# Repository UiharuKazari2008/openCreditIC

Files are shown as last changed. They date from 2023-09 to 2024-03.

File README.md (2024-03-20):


# openCreditIC / PayPass
Cheap Networked RFID Reader(s) and cloud-free server for arcade cabinet credit payments. Uses card serial number for ID and local server to manage cards and balances

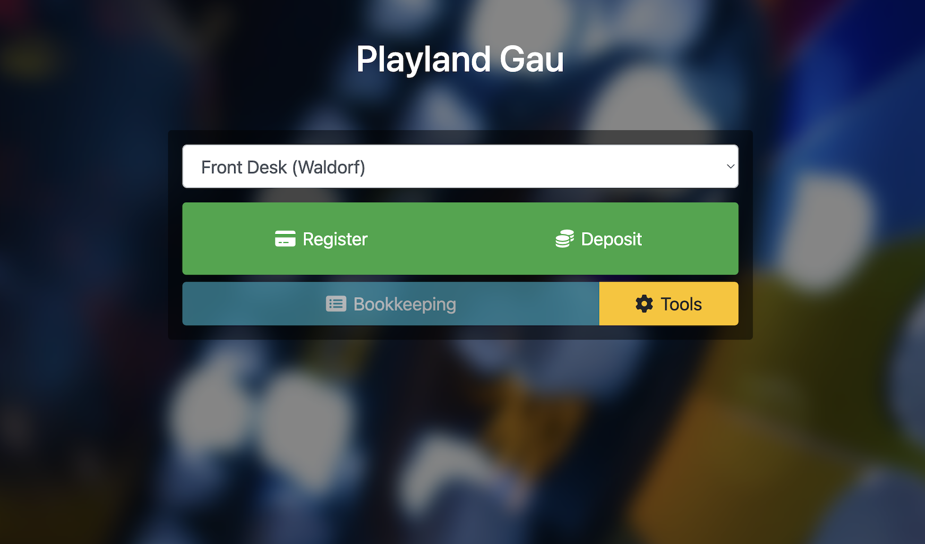
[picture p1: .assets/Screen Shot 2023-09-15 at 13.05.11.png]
Screen Shot 2023-09-15 at 13.05.11.png


## Sequenzia App Support





## NOTICE
At this time, I don't take responsibility for any damages caused if this is used commercially. Once this warning is removed you can consider the software to be "production" ready. More testing and feedback is still required

Please create issues to address feature requests and report bugs.

## Features
* ESP32-based RFID Card reader designed for low cast and easy build
* No Internet Access Required! *(after npm install)*
* Local Database
* Simple Web Interface for day to day tasks
* Per-User Multi-Card management
* Per-User Credit management
* Card and User Locking
* Toggleable Free Play (User, Machine, and Global)
* Per-machine Credit Cost
* Currency Mode Support (1 Credit = 100 Yen/Dollar/Euro)
* Cooldown and Anti-Hogging
  * X Credits per X Minutes
  * Anti-hogging can be used to set max number of credits per minutes to prevent hogging of cabinets
* Addressable POS Card Reader to provision cards and add credits
* Credit Withdraw History
* Credit Deposit History
* Supports multiple sites/locations
* HappyCAB MCU serial communication
  * Enable state toggle
  * Send coin blocker state
  * Use reader display for messageing 

## TODO
* VFD RS232 Communication (Currently requires AMaverlousDisplay)
* Encrypted communication

## Integrations
Supports various other ACR developed Arcade solutions
- AMaverlousDisplay: Displaying Information on WACCA Cabinets
- AmusementVISION: Displaying Information on video outputs
- Supports simple URL callbacks for:
  - On Credit Dispensed
  - On Valid Card Tap when Coin Blocked is activated
    - Example: Power on cabinet when powered off
- HappyCAB Cabinet MCU I/O and Display
- Connections to Sequenzia as a Embedded Application

## Installation
1. Install NodeJS on your system of choice
2. Clone this Git repo and cd into it
3. `npm install`
4. Create `config.json`
```json
{
  "arcade_name": "Arcade Name",
  "device_key": "API_KEY_FOR_CARD_READERS",
  "web_key": "WEB_ACCESS_API_KEY", /*If removed there is no login required*/
  "show_delete_actions": false /*Shows the Delete Card and Delete User Options*/
}
```
5. `node ./card-server.js`
6. Configure your arcade using the Configuration section
7. Open the web interface `http://localhost:1777/?key=WEB_ACCESS_API_KEY`

Use something like pm2 or systemd to run as a daemon 

## Example Card Reader Designs
Here are card readers that I have made and implemented as an example
### WACCA (Built into lower panel)
The card reader is mounted in the extra open window beside the coin slot<br/>
All The hardware in this example is in-assessable to the user<br/>
The relay is mounted flat to prevent bumping to insert credits<br/>
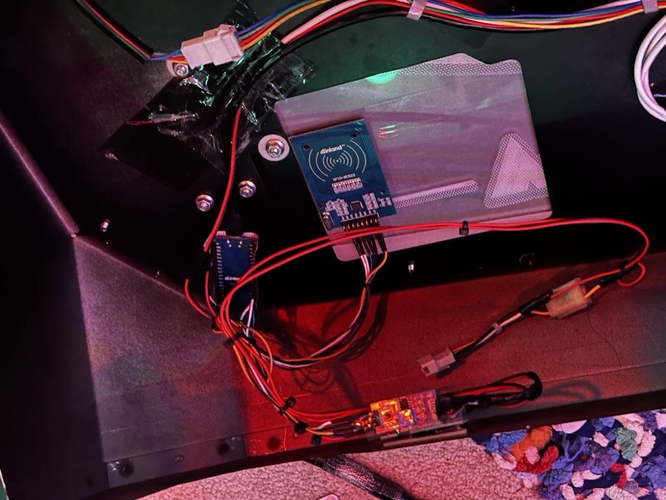
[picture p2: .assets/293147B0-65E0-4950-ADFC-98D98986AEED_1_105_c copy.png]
293147B0-65E0-4950-ADFC-98D98986AEED_1_105_c copy.png
<br/>

### Chunithm (Builtin to slider)
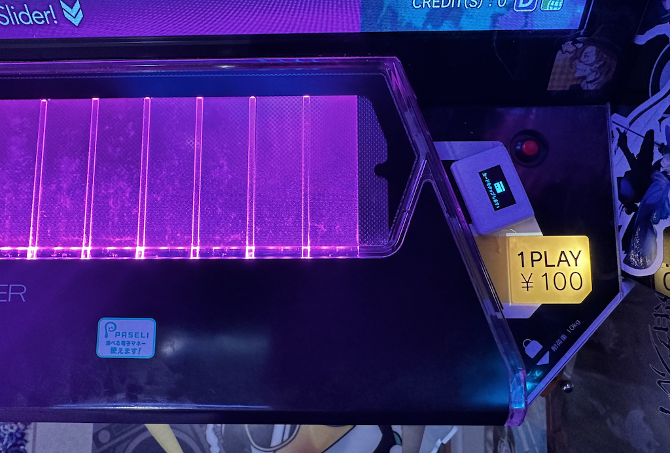
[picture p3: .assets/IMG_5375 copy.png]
IMG_5375 copy.png
<br/>
The card reader is mounted inside the ground slider, Foam backing is to prevent reader from getting to close to the metal backplate and causing issues with the reader<br/>
LED is mounted next to the "per play" indicator and is boxed to increase brightness<br/>
OLED Display is mounted over the coin slot<br/>
Button is added for future features<br/> 
The relay is mounted flat to prevent bumping to insert credits<br/>
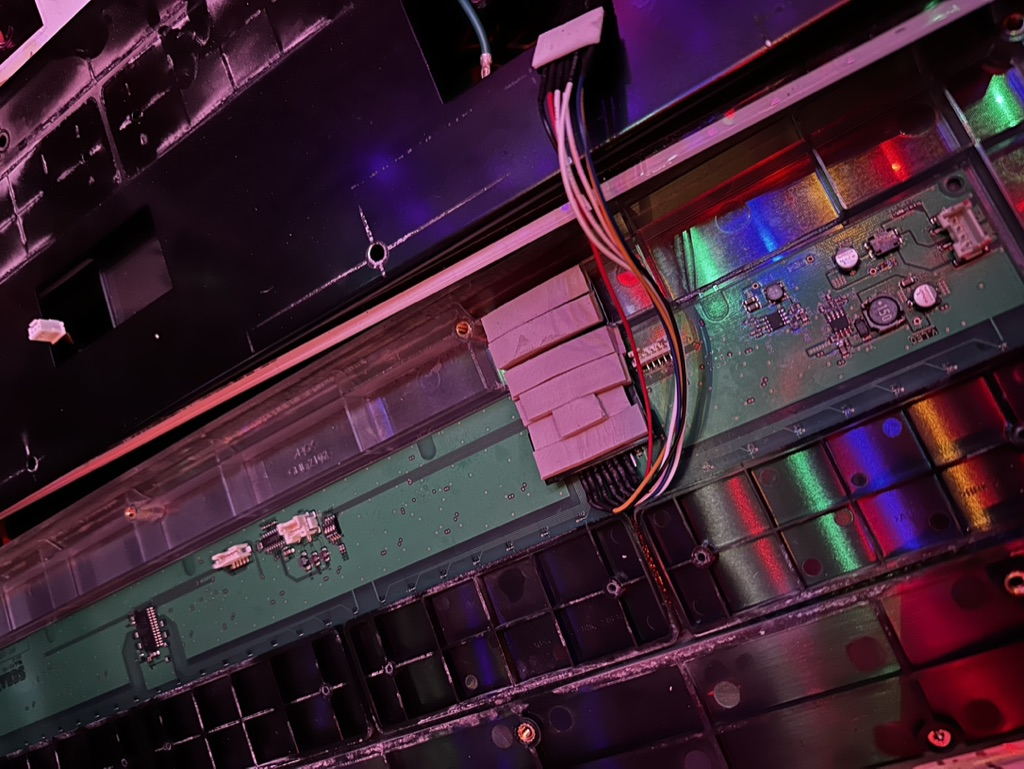
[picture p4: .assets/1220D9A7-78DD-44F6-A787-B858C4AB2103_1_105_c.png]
<br/>
10F6503A-9D1E-43A1-B554-D1E3282296A3_1_105_c copy.png<br/>

### POS Card Reader (with coin slot replacement reader)
Using the coin slot replacement reader design mounted on project box with the MCU inside.<br/>
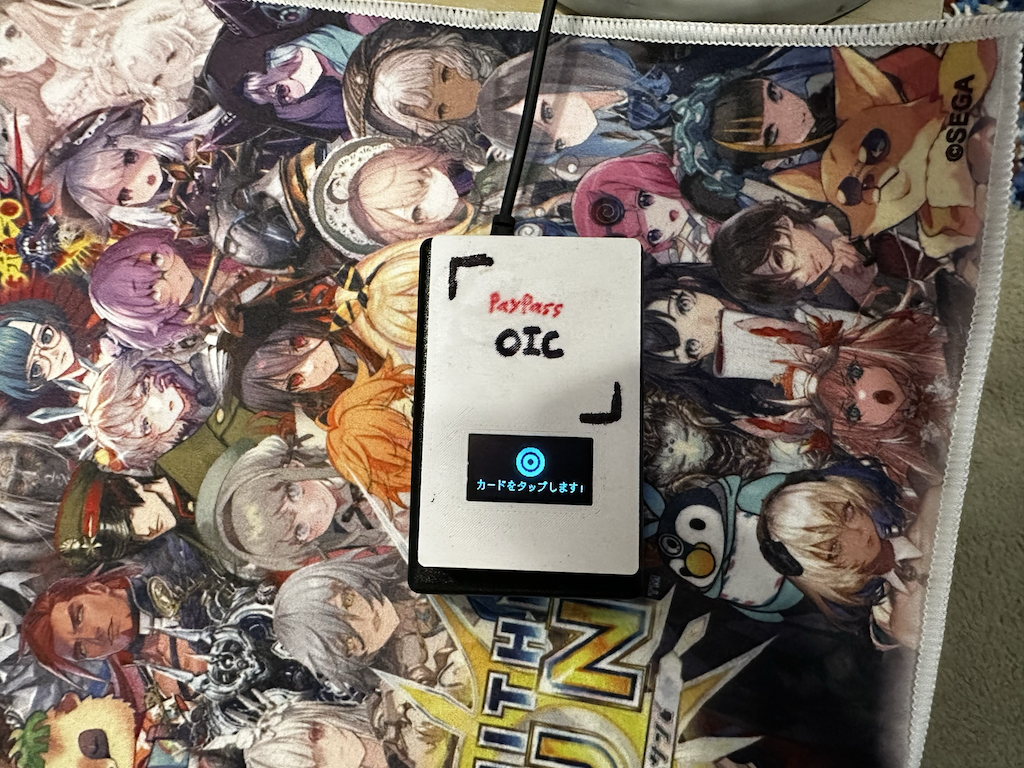
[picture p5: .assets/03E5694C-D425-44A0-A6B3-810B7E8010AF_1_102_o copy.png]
03E5694C-D425-44A0-A6B3-810B7E8010AF_1_102_o copy.png
<br/>
DED6BF8A-4EB7-40FF-B5D4-94D3E9F0AC93_1_102_o copy.png<br/>
Mounting screws are designed to work with most coin slots

## 3D printable designs
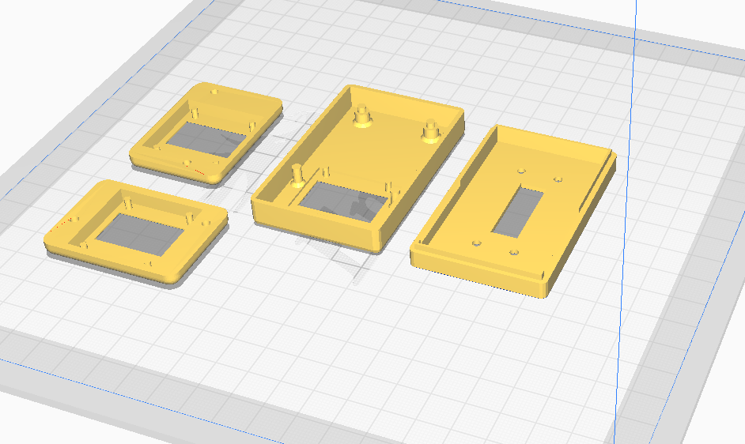
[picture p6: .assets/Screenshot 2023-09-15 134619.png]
Screenshot 2023-09-15 134619.png
<br/>
See the included STL files inside the `./printable` folder

## Card Reader Hardware
### Warning
It is expected that th card readers and the server are on there on dedicated wireless network in the case that this is running in a public arcade. As this is updated more security will be added.
### Configuration File
Create `config.h` inside the CardReader-* folder
```c
const char *ssid = "OCI_NET";
const char *password = "OCI_NET_SECURE029587";
const char *apiUrl = "http://192.168.0.2:1777/"; // URL to access central server
const char *deviceKey = "API_KEY_FOR_CARD_READERS"; // device_key from config.json

// Enable Remote Access
#define REMOTE_ACCESS
// Use Slimline 128x32 display
//#define DISPLAY_I2C_128x32
// Use alternative I2C card reader
//#define RFID_I2C
// Enable Multicore Tasking
#define MULTICORE_ENABLE
```
### Hardware
Any Optional hardware can be ommited and the reader will work the same
* ESP32 Dev Module
* RFID-RC522 RFID Module
* Credit Trigger
  * 5v/3.3v Relay with trigger on HIGH
  * or Optocoupler Isolation Board
* Coin Enable
  * LED + Digital LDR with trigger on HIGH
  * or Optocoupler Isolation Board (12v Input)
* RGB LED (WS2812) ***(Optional, Not Required)***
* OLED Display (SSD1306 128X64 I2C) ***(Optional, Suggested)***

### Pinout
* RFID-RC522
  * SDA/NSS/Slave Select -> **IO16**
  * SCK/Clock -> **IO18**
  * MOSI -> **IO23**
  * MISO -> **IO19**
  * GND -> **GND Bus**
  * RST -> **IO17**
  * 3.3v -> **3.3v Bus**
* Credit Add Relay
  * GND -> **GND Bus**
  * Trigger -> **IO13**
  * 5v -> **5v Bus**
* Coin Blocker
  * GND -> **GND Bus**
  * DO -> **IO14**
  * 3.3v -> **3.3v Bus**
* WS2812 Indicator LED *(Optional)*
  * GND -> **GND Bus**
  * IN -> **IO12**
  * 5v -> **5v Bus**
* I2C OLED Display *(Optional)*
  * GND -> **GND Bus**
  * SCL/Clock -> **IO22**
  * SDA/Data -> **IO21**
  * 5v -> **5v Bus**

### Flashing Firmware
* Connect via USB and launch Arduino IDE
* Install the following libraries
  * MFRC522
  * FastLED
  * ArduinoJSON
  * U8G2
* Open the project
  * CardReader-Game - Designed for games
  * CardReader-POS - Designed for POS reader (No Relay/No Coin Blocker)
* Set the following varibles
  * ssid - WiFi network Name
  * password - WiFi network password
  * apiUrl - IP/FQDN to access the server
  * deviceKey - device_key from config.json
* Build and Flash your card readers

## Configuration
Use the following URLs to set settings with your server<br/>
Add Commands need `key=API_KRY` to authenticate<br/>
* `/set/arcade/cost/<NUMBER>`: Set Per Play Cost
  * `/set/machine/cost/<MAC_ADDRESS>/<NUMBER>` (Per Machine)
* `/set/arcade/low_balance/<NUMBER>`: Set Low Balance Alert 
  * When users wallet balance falls below this number the display will display a warning and the LED will flash
* `/set/arcade/currency/<NUMBER>`: Set the currency to credit multiplier (use "null" as value to disable)
  * Once set Credits will be prefixed with Yen or Dollar symbol and will be multiplied based on that value
* `/set/arcade/freeplay/<enable or disable>`: Sets global freeplay mode
  * `/set/machine/freeplay/<MAC_ADDRESS>/<enable or disable>`: (Set Machine Freeplay)
* `/set/arcade/cooldown/<Credits:NUMBER>/<Minutes:NUMBER>`: Cooldown timeout - Sets max number of credits per X minutes
* `/set/arcade/antihog/<Credits:NUMBER>/<Minutes:NUMBER>`: Antihogging per machine timeout - Sets max number of credits per X minutes
  * `/set/machine/antihog/<Credits:NUMBER>/<Minutes:NUMBER>`: (Set Machine)
* `/set/arcade/japanese/<enable or disable>`: Enable Japanese Text and Currency
  * `/set/machine/japanese/<MAC_ADDRESS>/<enable or disable>`: (Set Machine)
* `/create/pos/<MAC_ADDRESS>`: Set up a POS reader
  * `name=`: Reader Name
  * `location=`: Reader Location

### Advanced
* `/set/machine/vfd/<MAC_ADDRESS>/<VFD_IP>/<VFD_PORT>`: Set VFD connection
* `/set/machine/blocked_callback/<MAC_ADDRESS>/<URL_ENCODED_URL>`: URL to call on blocked tap
* `/set/machine/withdraw_callback/<MAC_ADDRESS>/<URL_ENCODED_URL>`: URL to call on credit dispensed

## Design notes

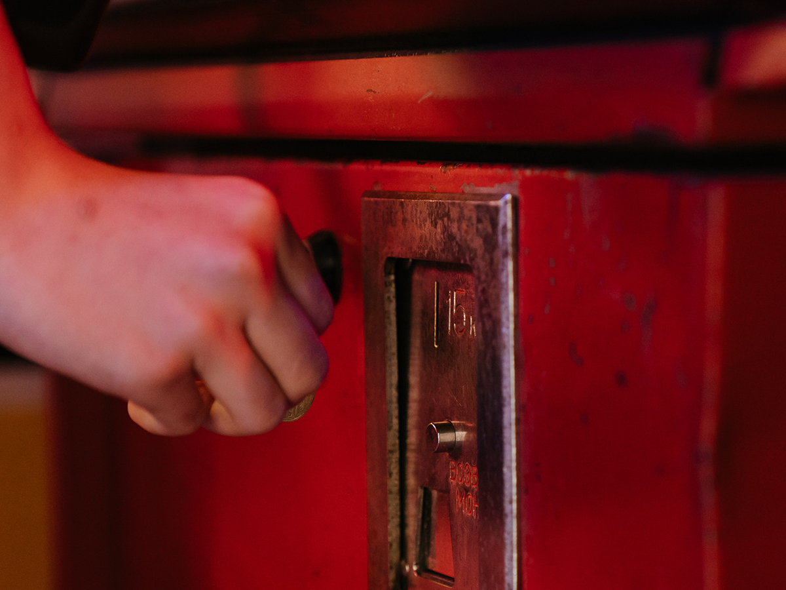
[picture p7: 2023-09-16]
ui_images/seq-launch.jpg

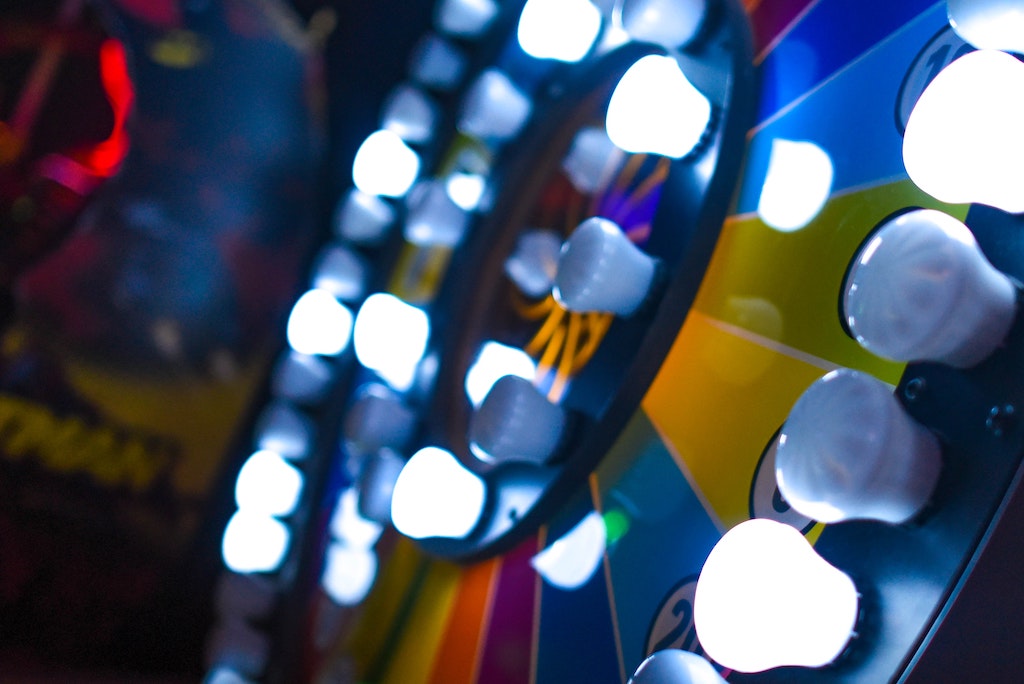
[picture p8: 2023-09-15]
ui_images/background.jpg

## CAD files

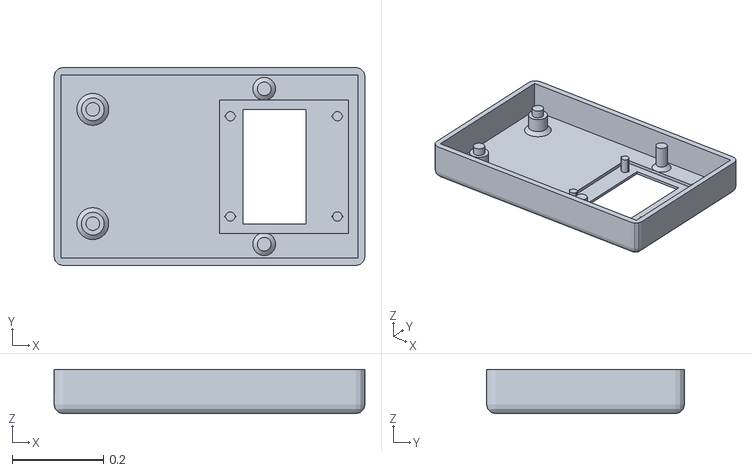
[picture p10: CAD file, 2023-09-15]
printable/chun_coin_with_display_landscape_case.stl
0.681 x 0.434 x 0.0969

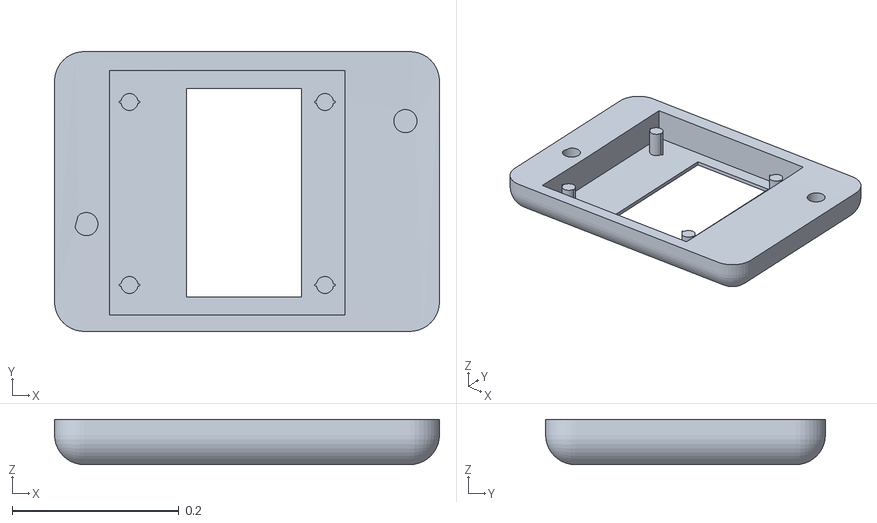
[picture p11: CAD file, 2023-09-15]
printable/chun_coin_with_display_landscape.stl
0.462 x 0.336 x 0.0543

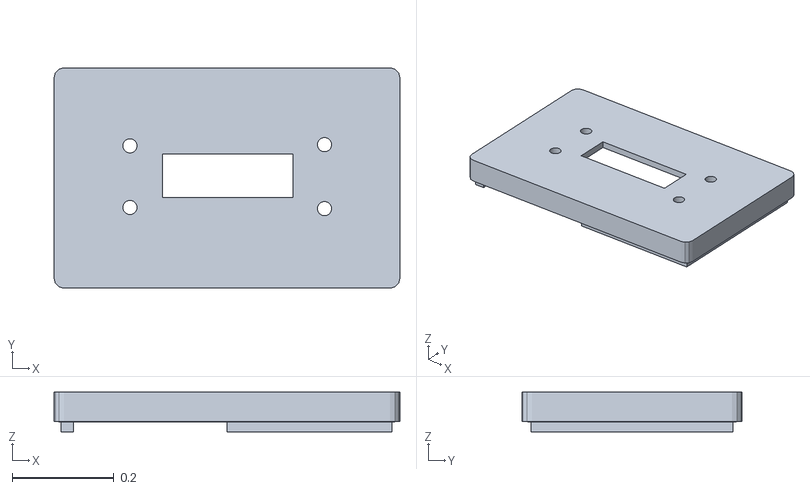
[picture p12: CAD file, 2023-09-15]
printable/chun_coin_with_display_landscape_case_back.stl
0.68 x 0.434 x 0.0786

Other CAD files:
printable/chun_coin_with_display.stl

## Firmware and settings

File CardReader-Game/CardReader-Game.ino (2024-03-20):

#include <Wire.h>
#include <Adafruit_PN532.h>
#include <SPI.h>
#include <MFRC522.h>
#include <WebServer.h>
#include <WiFi.h>
#include <HTTPClient.h>
#include <U8g2lib.h>  // Include the U8g2 library for OLED display.
#include <ArduinoJson.h>
#include <FastLED.h>
#include "images.h"
#include "config.h"
#include "melody.h"

#define SS_PIN 5      // Define the SS pin (Slave Select) for the RFID module.
#define RST_PIN 15     // Define the RST pin for the RFID module.
#define RELAY_PIN 13   // Define the pin connected to the relay.
#define BLOCK_PIN 14   // Define the pin connected to the LDR for Coin Blocking from cab
#define BUTTON_PIN 4   // Button used for front panel button
#define LED_PIN 12     // Define the pin connected to the WS2812 LED strip.
#define NUM_LEDS 1     // Define the number of LEDs in the strip.
#define HAPPYCAB_TX 2 // Define the pin to communicate with the cabinet MCU (if used)
#define HAPPYCAB_RX 4 // Define the pin to communicate with the cabinet MCU (if used)
#define LONG_PRESS_TIME 1 // Define long press time (sec) for long press action on button
#define EXTRA_PRESS_TIME 3 // Define long press time (sec) for long press action on button

CRGB leds[NUM_LEDS];  // Create an array of CRGB colors for the LEDs.
#ifdef RFID_I2C
Adafruit_PN532 nfc(21, 22);
#else
MFRC522 mfrc522(SS_PIN, RST_PIN);  // Create an MFRC522 instance.
#endif

#ifdef DISPLAY_I2C_128x32
U8G2_SSD1306_128X32_UNIVISION_F_HW_I2C u8g2(U8G2_R0);
#else
U8G2_SSD1306_128X64_NONAME_F_HW_I2C u8g2(U8G2_R0);
#endif
#ifdef REMOTE_ACCESS
WebServer server(80);
#endif
#ifdef HAPPYCAB_ENABLE
HardwareSerial cardReaderSerial(2);
#endif
TaskHandle_t Task1;
TaskHandle_t Task2;
TaskHandle_t Task3;
TaskHandle_t Task4;

int enableState = 0;
int blockState = 0;
int blockOverride = 0;
int displayState = -1;
bool waitingForUnblock = false;
bool lastButtonState = false;
bool handledButtonState = false;
unsigned long buttonPressStartTime = 0;
int mcuState = -1;
int displayTimeout = 0;
int previousDisplayTimeout = 0;
int typeOfMessage = -1;
int messageIcon = 0;
String messageText = "";
bool isJpnMessage = false;
int brightMessage = 1;
bool invertMessage = false;

int lastCheckIn = 0;

char* sys_name = "";
bool sys_jpn = false;
bool sys_free_play = false;
bool sys_currency_mode = false;
bool sys_button_remote_action = false;
float sys_currency_rate = 1;
float sys_cost = 1;
bool sys_callbackOnBlockedTap = false;

void setup() {
  Serial.begin(115200);
  pinMode(RELAY_PIN, OUTPUT);
  pinMode(21, OUTPUT);
  pinMode(22, OUTPUT);
  pinMode(BLOCK_PIN, INPUT);
  pinMode(BUTTON_PIN, INPUT_PULLUP);
  digitalWrite(RELAY_PIN, LOW);                           // Initially, set the relay to OFF.
  FastLED.addLeds<WS2812, LED_PIN, GRB>(leds, NUM_LEDS);  // Initialize the LED strip.
  u8g2.begin();
  u8g2.enableUTF8Print();
  setLEDs(CRGB::Black);
  FastLED.setBrightness(255);
  FastLED.clear();
  FastLED.show();
  bootScreen("HARDWARE");
  #ifdef RFID_I2C
    Wire.begin(21, 22);
    nfc.begin();
    uint32_t versiondata = nfc.getFirmwareVersion();
    if (!versiondata) {
      Serial.println("Didn't find PN53x board");
      bootScreen("NFC FAILURE");
      while (1)
        ;
    }
    Serial.print("Found chip PN5");
    Serial.println((versiondata >> 24) & 0xFF, HEX);
    Serial.print("Firmware ver. ");
    Serial.print((versiondata >> 16) & 0xFF, DEC);
    Serial.print('.');
    Serial.println((versiondata >> 8) & 0xFF, DEC);
    nfc.setPassiveActivationRetries(0x0A);
    nfc.SAMConfig();
  #else
    SPI.begin();         // Initialize SPI communication.
    mfrc522.PCD_Init();  // Initialize the RFID module.
    mfrc522.PCD_SetAntennaGain(mfrc522.RxGain_48dB);
  #endif
  checkWiFiConnection();

  #ifdef REMOTE_ACCESS
    server.on("/test/block", [=]() {
      if (blockOverride == 0) {
        blockOverride = 1;
      } else {
        blockOverride = 0;
      }
      enableState = 1;
      Serial.print("Set coin blocker overide: ");
      Serial.println((blockOverride == 1) ? "Overided" : "Normal");
      server.send(200, "text/plain", (blockOverride == 1) ? "Overided Coin Enable" : "Normal Mode");
    });
    server.on("/enable", [=]() {
      enableState = 1;
      server.send(200, "text/plain", "OK");
    });
    server.on("/disable", [=]() {
      enableState = 0;
      server.send(200, "text/plain", "OK");
    });
    server.on("/status", [=]() {
      String assembledOutput = "";
      assembledOutput += ((enableState == 0) ? "Disabled" : ((blockState == 1) ? "Blocked" : "Enabled"));
      server.send(200, "text/plain", assembledOutput);
    });
    server.on("/credit", [=]() {
      String assembledOutput = "";
      handleDispenseCoin();
      server.send(200, "text/plain", "OK");
    });
    server.on("/reboot", [=]() {
      String assembledOutput = "";
      server.send(200, "text/plain", "OK");
      ESP.restart();
    });
    server.begin();
    Serial.println("Remote Access Enabled");
  #endif

  #ifdef HAPPYCAB_ENABLE
    bootScreen("CR_LINK");
    cardReaderSerial.begin(9600, SERIAL_8N1, 16, 17);
    if (!cardReaderSerial) {
      bootScreen("CARDREADER_FAIL_1");
      Serial.println("Serial Port did no load!");
      while (1) { // Don't continue with invalid configuration
        delay (1000);
      }
    } else {
      cardReaderSerial.println("HELLO::NO_DATA_ED_");
    }
    delay (500);
    enableState = 0;
  #else
    enableState = 1;
  #endif
  Serial.println("Reader is ready to init");
  #ifdef MULTICORE_ENABLE
    bootScreen("BOOT_HCCL");
    //create a task that will be executed in the Task2code() function, with priority 1 and executed on core 1
    xTaskCreatePinnedToCore(
                      cardReaderTXLoop,   /* Task function. */
                      "mcuTX",     /* name of task. */
                      10000,       /* Stack size of task */
                      NULL,        /* parameter of the task */
                      1,           /* priority of the task */
                      &Task3,      /* Task handle to keep track of created task */
                      1);          /* pin task to core 1 */
    delay(500);
    //create a task that will be executed in the Task2code() function, with priority 1 and executed on core 1
    xTaskCreatePinnedToCore(
                      cardReaderRXLoop,   /* Task function. */
                      "mcuRX",     /* name of task. */
                      10000,       /* Stack size of task */
                      NULL,        /* parameter of the task */
                      1,           /* priority of the task */
                      &Task4,      /* Task handle to keep track of created task */
                      1);          /* pin task to core 1 */
    delay(500);
    bootScreen("BOOT_CPU1");
    xTaskCreatePinnedToCore(
                      cpu2Loop,   /* Task function. */
                      "Watchdog",     /* name of task. */
                      10000,       /* Stack size of task */
                      NULL,        /* parameter of the task */
                      1,           /* priority of the task */
                      &Task1,      /* Task handle to keep track of created task */
                      0);          /* pin task to core 0 */
    delay(250);
    bootScreen("BOOT_CPU2");
    delay(250);
    //create a task that will be executed in the Task2code() function, with priority 1 and executed on core 1
    xTaskCreatePinnedToCore(
                      cpu1Loop,   /* Task function. */
                      "ReaderTask",     /* name of task. */
                      10000,       /* Stack size of task */
                      NULL,        /* parameter of the task */
                      1,           /* priority of the task */
                      &Task2,      /* Task handle to keep track of created task */
                      1);          /* pin task to core 1 */
    delay(500);
  #endif
}
void loop() {
  #ifdef MULTICORE_ENABLE
    // Handled by tasks
  #else
    int time_in_sec = esp_timer_get_time() / 1000000;
    if (time_in_sec >= 86400) {
      Serial.println("Daily Reboot");
      ESP.restart();
    } else if (lastCheckIn <= time_in_sec - 18000) {
      Serial.println("Check in");
      getConfig(false);
    }
    checkWiFiConnection();
    #ifdef REMOTE_ACCESS
      server.handleClient();
    #endif
    runtime();
  #endif
}

//////////////////////
// System Functions //
//////////////////////

// Check WiFi or Connect
void checkWiFiConnection() {
  if (WiFi.status() != WL_CONNECTED) {
    setLEDs(CRGB::Magenta);
    bootScreen("NETWORK");
    Serial.println("WiFi not connected. Attempting to reconnect...");
    WiFi.hostname("SimpleCard");
    WiFi.disconnect(true);
    WiFi.begin(ssid, password);
    WiFi.setAutoReconnect(true);
    WiFi.persistent(true);
    int tryCount = 0;
    while (WiFi.status() != WL_CONNECTED) {
      if (digitalRead(BUTTON_PIN) == LOW) {
        ESP.restart();
      }
      if (tryCount > 10) {
        ESP.restart();
      }
      delay(1000);
      Serial.print(".");
      tryCount++;
    }
    Serial.println("\nConnected to WiFi");
    Serial.print("IP address: ");
    Serial.println(WiFi.localIP());
    Serial.print("MAC address: ");
    Serial.println(WiFi.macAddress());
    bootScreen("CONFIG");
    getConfig(true);
    bootScreen("READY");
    delay(250);
  }
}
// Get Reader Config
void getConfig(bool firstStart) {
  Serial.println("Refreshing system config....");
  HTTPClient http;
  String url = String(apiUrl) + "get/machine/" + WiFi.macAddress() + ((firstStart == true) ? "/init" : "/checkin") + "?key=" + deviceKey;
  Serial.println("Sending GET request to: " + url);
  http.begin(url);
  int httpCode = http.GET();
  String httpResponse = http.getString();
  http.end();
  Serial.println("HTTP Response code: " + String(httpCode));
  if (httpCode == 200) {
    Serial.println(httpResponse);
    DynamicJsonDocument doc(1024);
    deserializeJson(doc, httpResponse);
    //sys_name = doc["name"];
    sys_cost = doc["cost"];
    sys_free_play = doc["free_play"];
    sys_currency_mode = doc["currency_mode"];
    sys_currency_rate = (sys_currency_mode == true) ? doc["currency_rate"] : 0;
    sys_jpn = doc["japanese"];
    sys_button_remote_action = doc["button_callback"];
    sys_callbackOnBlockedTap = doc["has_blocked_callback"];
    lastCheckIn = esp_timer_get_time() / 1000000;
  } else if (httpCode >= 400 && httpCode <= 499) {
    while(true) {
      if (firstStart == true) {
        bootScreen("AUTH FAIL");
        delay(5000);
        bootScreen(WiFi.macAddress());
        delay(60000);
        ESP.restart();
      } else {
        ESP.restart();
      }
    };
  } else {
    Serial.println("Can't get config");
    if (firstStart == true) {
      bootScreen("AUTH FAIL");
      delay(5000);
      ESP.restart();
    }
  }
}
// Gets Cards UID
String getUID() {
  String uid = "";
  #ifdef RFID_I2C
    uint8_t success;
    uint8_t uidValue[] = { 0, 0, 0, 0, 0, 0, 0 };
    uint8_t uidLength;
    success = nfc.readPassiveTargetID(PN532_MIFARE_ISO14443A, uidValue, &uidLength);
    if (success) {
      for (uint8_t i = 0; i < uidLength; i++) {
        uid += String(uidValue[i], HEX);
      }
      uid.toUpperCase();
    }
  #else
    for (byte i = 0; i < mfrc522.uid.size; i++) {
      uid += String(mfrc522.uid.uidByte[i], HEX);
    }
    uid.toUpperCase();
  #endif
  return uid;
}


//////////////////////
// Action Handelers //
//////////////////////

// Primary Loop function
#ifdef MULTICORE_ENABLE
void cpu1Loop( void * pvParameters ) {
  Serial.print("Primary Task running on core ");
  Serial.println(xPortGetCoreID());

  for(;;) {
    runtime();
  }
}
// Secoundary Loop Function
void cpu2Loop( void * pvParameters ) {
  Serial.print("Secoundary Task running on core ");
  Serial.println(xPortGetCoreID());

  for(;;) {
    int time_in_sec = esp_timer_get_time() / 1000000;
    int currentMillis = millis();
    if (time_in_sec >= 86400) {
      Serial.println("Daily Reboot");
      ESP.restart();
    } else if (lastCheckIn <= time_in_sec - 18000) {
      Serial.println("Check in");
      getConfig(false);
    }
    checkWiFiConnection();
    #ifdef BEEPER_ENABLE
    if (startMelody == true) {
      if (currentMillis - previousMelodyMillis >= pauseBetweenNotes) {
        previousMelodyMillis = currentMillis;
        if (melodyPlay == 0) {
          playMelody(credit_tone, credit_tone_dur, sizeof(credit_tone_dur) / sizeof(int));
        } else if (melodyPlay == 1) {
          playMelody(blocked_tone, blocked_tone_dur, sizeof(credit_tone_dur) / sizeof(int));
        }
      }
    }
    #endif
    #ifdef REMOTE_ACCESS
      server.handleClient();
    #endif
  }
}
int last_card_response = -1;
String last_card_data = "";
bool send_boot = false;
bool send_button_0 = false;
bool send_button_1 = false;
bool send_button_2 = false;
bool send_button_3 = false;
bool send_button_4 = false;
bool send_button_5 = false;
#ifdef HAPPYCAB_ENABLE
// MCU Talk Loop Function
void cardReaderTXLoop( void * pvParameters ) {
  for(;;) {
    cardReaderSerial.println("COIN_ENABLE::" + String((digitalRead(BLOCK_PIN) == LOW || blockOverride == 1) ? "1" : "0") + "::");
    delay(100);
    if (last_card_response != -1) {
      // Send Credit If Needed
      if (blockOverride == 1 && (last_card_response >= 200 && last_card_response < 300)) {
        for (int i = 0; i < 2; i++) {
          cardReaderSerial.println("GPIO::CREDIT::");
          delay(100);
        }
      }
      for (int i = 0; i < 2; i++) {
        cardReaderSerial.println("COIN_DISPENSE::" + String(last_card_response) +  "::" + last_card_data + "::");
        delay(100);
      }
      last_card_response = -1;
      last_card_data = "";
    } else if (send_boot == true) {
      // Send Boot Command
      send_boot = false;
      for (int i = 0; i < 2; i++) {
        cardReaderSerial.println("BOOT_REQUEST::NO_DATA::");
        delay(100);
      }
    } else if (send_button_0 == true) {
      // Send Boot Command
      send_button_0 = false;
      for (int i = 0; i < 2; i++) {
        cardReaderSerial.println("BUTTON_REQUEST::0::");
        delay(100);
      }
    } else if (send_button_1 == true) {
      // Send Boot Command
      send_button_1 = false;
      for (int i = 0; i < 2; i++) {
        cardReaderSerial.println("BUTTON_REQUEST::1::");
        delay(100);
      }
    } else if (send_button_2 == true) {
      // Send Boot Command
      send_button_2 = false;
      for (int i = 0; i < 2; i++) {
        cardReaderSerial.println("BUTTON_REQUEST::2::");
        delay(100);
      }
    } else if (send_button_3 == true) {
      // Send Boot Command
      send_button_3 = false;
      for (int i = 0; i < 2; i++) {
        cardReaderSerial.println("BUTTON_REQUEST::3::");
        delay(100);
      }
    } else if (send_button_4 == true) {
      // Send Boot Command
      send_button_4 = false;
      for (int i = 0; i < 2; i++) {
        cardReaderSerial.println("BUTTON_REQUEST::4::");
        delay(100);
      }
    } else if (send_button_5 == true) {
      // Send Boot Command
      send_button_5 = false;
      for (int i = 0; i < 2; i++) {
        cardReaderSerial.println("BUTTON_REQUEST::5::");
        delay(100);
      }
    }
  }
}
void cardReaderRXLoop( void * pvParameters ) {
  for(;;) {
    if (cardReaderSerial.available()) {
      static String receivedMessage = "";
      char c;
      bool messageStarted = false;

      while (cardReaderSerial.available()) {
        c = cardReaderSerial.read();
        Serial.print(c);
        if (c == '\n') {
          if (!receivedMessage.isEmpty()) {
            handleCRMessage(receivedMessage);
            //Serial.println("Received: " + receivedMessage);
          }
          receivedMessage = "";
        } else {
          receivedMessage += c;
        }

      }
    } else {
      delay(1);
    }
  }
}

#endif
#endif
// Primary Loop Function
void runtime() {
  if (displayTimeout != 0) {
    unsigned long currentMillis = millis();
    if (millis() - previousDisplayTimeout >= displayTimeout) {
      displayTimeout = 0;
      typeOfMessage = -1;
      messageIcon = 0;
      messageText = "";
      isJpnMessage = false;
      brightMessage = 1;
      invertMessage = false;
    } else if (displayState != -2) {
        if (typeOfMessage == 1) {
          displayCustomMessage(messageIcon, messageText, isJpnMessage, brightMessage, invertMessage);
        } else if (typeOfMessage == 0) {
          displayCustomMessageSingleLine(messageIcon, messageText, isJpnMessage, brightMessage, invertMessage);
        }
    }
  }
  if (digitalRead(BLOCK_PIN) == LOW || blockOverride == 1) {
      // Game Enabled
      if (blockState == 1) {
        // Was Previouly Blocked
        handleUnblocking();
      }
      if (enableState == 0) {
        // Disabled by Admin
        displayDisableReader();
      } else {
        // Enabled by Admin
        if (digitalRead(BUTTON_PIN) == LOW) {
          // Button is being pressed
          if (lastButtonState == false) {
            lastButtonState = true;
            handledButtonState = false;
            buttonPressStartTime = millis();
            #ifdef HAPPYCAB_ENABLE
            //
            #else
              displayButtonDisplayEnabled();
            #endif
          } else if (lastButtonState == true && handledButtonState == false && millis() - buttonPressStartTime >= (EXTRA_PRESS_TIME * 1000)) {
            // Extra Long press detected
            send_button_5 = true;
            handledButtonState = true;
          } 
        } else if (digitalRead(BUTTON_PIN) == HIGH && handledButtonState == true) {
          // Button was released and already handled
          lastButtonState = false;
          handledButtonState = false;
        } else if (digitalRead(BUTTON_PIN) == HIGH && lastButtonState == true) {
          // Button was released
          lastButtonState = false;
          #ifdef HAPPYCAB_ENABLE
            if (millis() - buttonPressStartTime >= (LONG_PRESS_TIME * 1000)) {
              // Long press detected
              send_button_3 = true;
            } else {
              // Short press detected
              send_button_1 = true;
            }
          #endif
        } else {
          // Normal State
          handleCardRead();
          displayStandbyScreen();
        }
      }
    } else if (waitingForUnblock == true) {
      // Waiting for game to enable reader
      displayBootUpReader();
    } else if (digitalRead(BLOCK_PIN) == HIGH) {
      // Game Disabled
      if (blockState == 0) {
        // Was Previouly Unblocked
        handleBlocked();
      }
      if (enableState == 0) {
        // Disabled by Admin
        sleepDevice();
      } else {
        // Enabled by Admin
        if (digitalRead(BUTTON_PIN) == LOW) {
          // Button is being pressed
          if (lastButtonState == false) {
            lastButtonState = true;
            buttonPressStartTime = millis();
            #ifdef HAPPYCAB_ENABLE
            //
            #else
              displayButtonDisplayDisabled();
            #endif
          } else if (lastButtonState == true && handledButtonState == false && millis() - buttonPressStartTime >= (EXTRA_PRESS_TIME * 1000)) {
            // Extra Long press detected
            send_button_4 = true;
            handledButtonState = true;
          } 
        } else if (digitalRead(BUTTON_PIN) == HIGH && handledButtonState == true) {
          // Button was released and already handled
          lastButtonState = false;
          handledButtonState = false;
        } else if (digitalRead(BUTTON_PIN) == HIGH && lastButtonState == true) {
          // Button was released
          lastButtonState = false;
          #ifdef HAPPYCAB_ENABLE
            if (millis() - buttonPressStartTime >= (LONG_PRESS_TIME * 1000)) {
              // Long press detected
              send_button_2 = true;
            } else {
              // Short press detected
              send_button_0 = true;
            }
          #endif
        } else if (sys_callbackOnBlockedTap == true) {
          // Normal State (With Waiting Card)
          handleCardRead();
          displayEcoModeScreen();
        } else {
          // Normal State
          sleepDevice();
        }
      }
    }
}
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

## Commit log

2023-09-05 Now able to call VFD and added non-led card reader
2023-09-15 Updated to docs
    [chun_coin_with_display.stl, chun_coin_with_display_landscape.stl, chun_coin_with_display_landscape_case.stl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]
2023-09-16 Cleaned up Arduino Code
2023-09-16 fixed ardino code and added new function to get config
    [CardReader-Game.ino]
2023-09-16 More fixed to arduino code
    [CardReader-Game.ino]
2023-09-17 updated some arduino code and chnaged value set for lang on readers
